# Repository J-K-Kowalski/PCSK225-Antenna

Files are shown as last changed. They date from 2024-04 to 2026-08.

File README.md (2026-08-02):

# PCSK225-Antenna

<ul>
<li>2026-08-02 - recalculate resistors value</li>
<li>2024-10-08 - fixed GND symbol</li>
<li>2024-06-18 - new version of Ferrite Holder</li>
</ul>

<p>This simple active antenna is designed to receive the time signal from the PCSK-225 transmitter in Solec Kujawski, Poland.

<p>It allows you to reliably receive UTC(pl) time frames transmitted by the <a href="https://e-czas.gum.gov.pl/e-czas-radio/" target=_blank>Central Office of Measures</a> using this transmitter. Receiver documentation is available at https://github.com/e-czasPL/TimeReceiver225kHz.

The project uses a ferrite antenna from a cheap and popular DCF receiver available, for example, on Aliexpress. Such an antenna has an inductance of approximately 1.5mH. You need to use 333pF capacitors (270pF + 56pF + trimmer 6-25pF) which will allow you to tune the resonant circuit to 225kHz.

The transistor BF545, MMBFJ108 (SMD) or BF245/J211 (THT) was used as an amplifier - only one should be installed.

If a long-wave ferrite antenna (from an old radio) with an inductance of about 4-6mH is used, the capacitors should be reduced to about 100pF.

<ul>
<li>In the /KiCAD folder, you will find a project in the KiCAD 10.0 format;
<li>In the /3D folder, you will find models of the holder and the entire antenna in STEP, STL formats;
</ul>

<p>The long wave signal of the First Polish Radio Program reaches a large part of Europe. You can see the coverage map below.

<p>
<table border=0 cellpadding=0 cellspacing=0 width=100%>
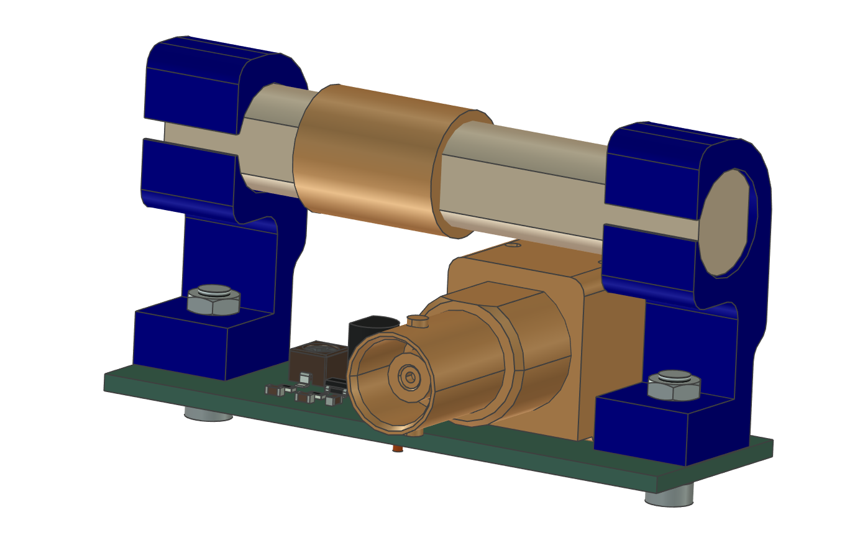
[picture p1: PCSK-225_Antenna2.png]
<tr><td>
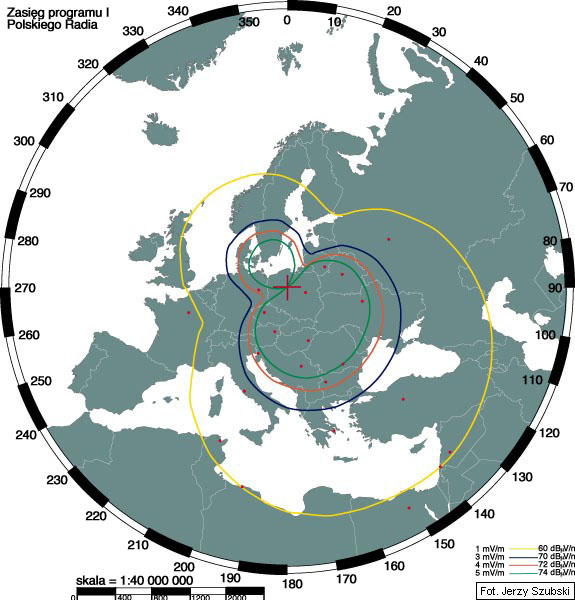
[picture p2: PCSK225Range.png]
</td><td></td></tr>
</table>

<ul>
<li>2024-06-18 - Nowa wersja modelu 3D do wydruku uchwytu na pręt ferrytowy</li>
</ul>

<p>Ta prosta aktywna antena jest zaprojektowana do odbioru sygnału czasu z nadajnika PCSK-225 w Solec Kujawski, Polska.

<p>Pozwala ona niezawodnie odbierać ramki czasu UTC(pl) nadawane przez <a href="https://e-czas.gum.gov.pl/e-czas-radio/" target=_blank>Główny Urząd Miar</a> za pomocą tego nadajnika. Dokumentacja odbiornika jest dostępna na https://github.com/e-CzasPL/TimeReceiver225kHz.

W projekcie użyto anteny ferrytowej od taniego i popularnego odbiornika DCF dostępnego np. na Aliexpress. Taka antena ma indukcyjność ok 1.5mH. Dlatego trzeba użyć kondensatorów 333pF (270pF + 56pF + trymer 6-25pF) co pozwoli zestroić obwód rezonansowy na 225 kHz.

Jako wzmacniacz użyto tranzystora BF545 lub MMBFJ108 (SMD) lub BF245/J211 (THT) - należy zamontować tylko jeden z nich.

Jeżeli zostanie użyta antena ferrytowa na fale długie (ze starego radia) o indukcyjności ok. 4-6mH to należy kondensatory zmniejszyć do ok 100pF.

<ul>
<li>W folderze /KiCAD znajdziesz projekt w formacie KiCAD 10;
<li>W folderze /3D znajdziesz modele uchwytu i całej anteny w formatach STEP, STL;
</ul>

<p>Sygnał fal długich Programu Pierwszego Polskiego Radia dociera do dużej części Europy. Powyżej możesz zobaczyć mapę zasięgu.

<p>Jerzy K. Kowalski<br>Marek Mańkowski

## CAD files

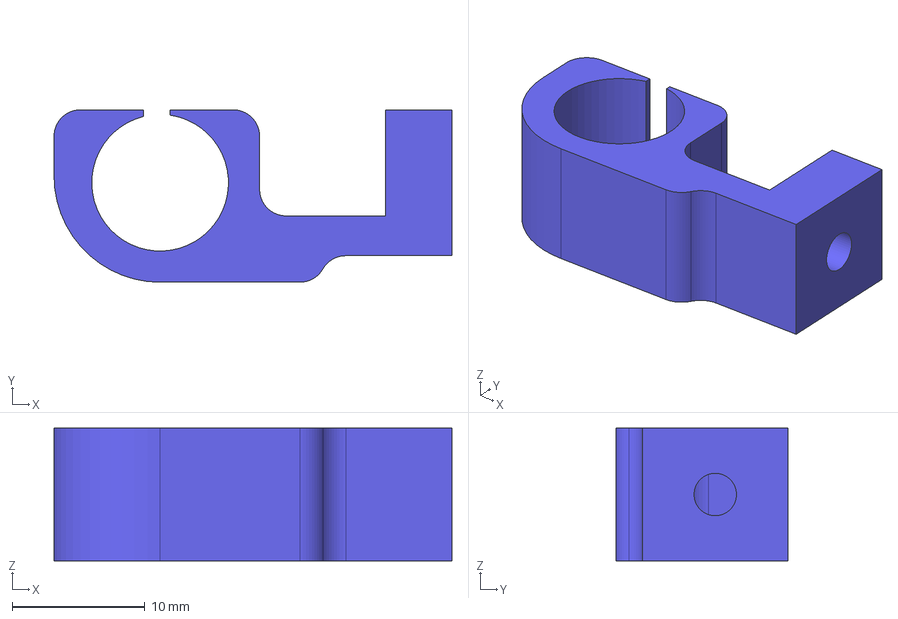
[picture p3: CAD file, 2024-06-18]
3D/FerriteHolder2.stp
30.0 x 13.0 x 10.00 mm

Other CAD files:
3D/FerriteHolder2.stl

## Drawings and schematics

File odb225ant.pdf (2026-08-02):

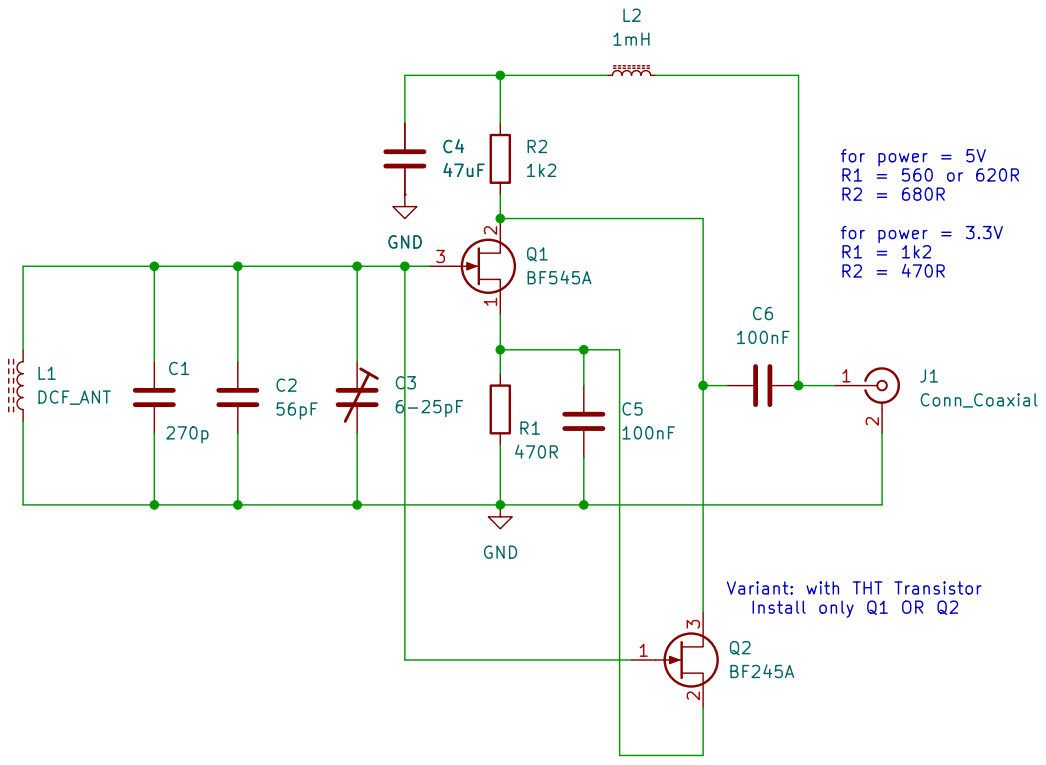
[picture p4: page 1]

Install only Q1 OR Q2 GND

Variant: with THT Transistor

Size: A4 | Rev:
KiCad E.D.A. 10.0.3 | Id: 1/1

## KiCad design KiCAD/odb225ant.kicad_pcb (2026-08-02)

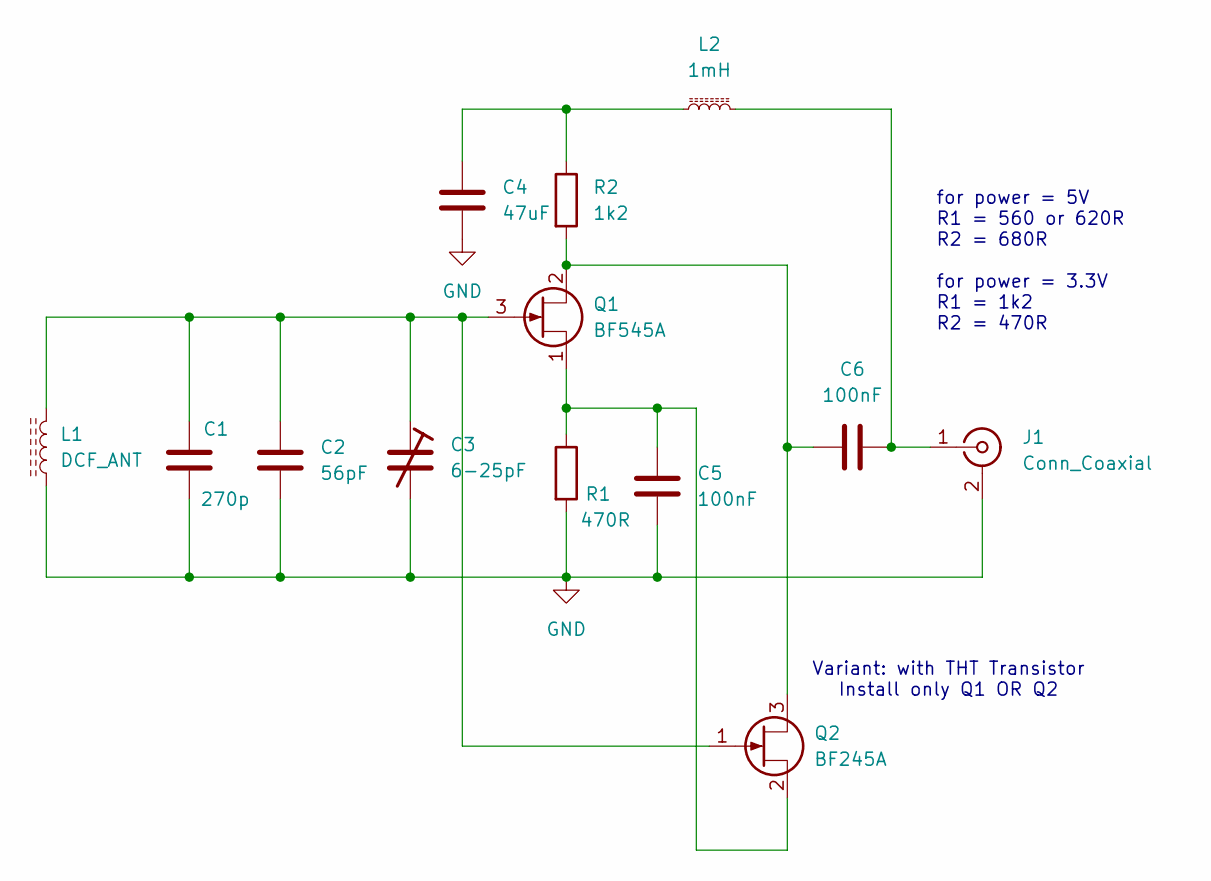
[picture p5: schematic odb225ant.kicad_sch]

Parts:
C1: 270p; C_0603_1608Metric_Pad1.08x0.95mm_HandSolder
C2: 56pF; C_0603_1608Metric_Pad1.08x0.95mm_HandSolder
C3: 6-25pF; C_Trimmer_Murata_TZB4-B
C4: 47uF; C_0603_1608Metric_Pad1.08x0.95mm_HandSolder
C5, C6: 100nF; C_0603_1608Metric_Pad1.08x0.95mm_HandSolder
J1: Conn_Coaxial; BNC_Horizontal
L1: DCF_ANT; PinHeader_1x02_P2.54mm_Vertical
L2: 1mH; L_Axial_L12.0mm_D5.0mm_P15.24mm_Horizontal_Fastron_MISC
Q1: BF545A; SOT-23
Q2: BF245A; TO-92_Inline
R1: 470R; R_0603_1608Metric_Pad0.98x0.95mm_HandSolder
R2: 1k2; R_0603_1608Metric_Pad0.98x0.95mm_HandSolder

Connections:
GND: C1.2, C2.2, C3.2, C4.2, C5.2, J1.2 (Ext), L1.2, R1.2
unnamed: C4.1, L2.1, R2.1
unnamed: C6.2, J1.1 (In), L2.2
unnamed: C6.1, Q1.2 (D), Q2.3 (D), R2.2
unnamed: C1.1, C2.1, C3.1, L1.1, Q1.3 (G), Q2.1 (G)
unnamed: C5.1, Q1.1 (S), Q2.2 (S), R1.1

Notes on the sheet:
Variant: with THT Transistor Install only Q1 OR Q2
for power = 5V R1 = 560 or 620R R2 = 680R for power = 3.3V R1 = 1k2 R2 = 470R

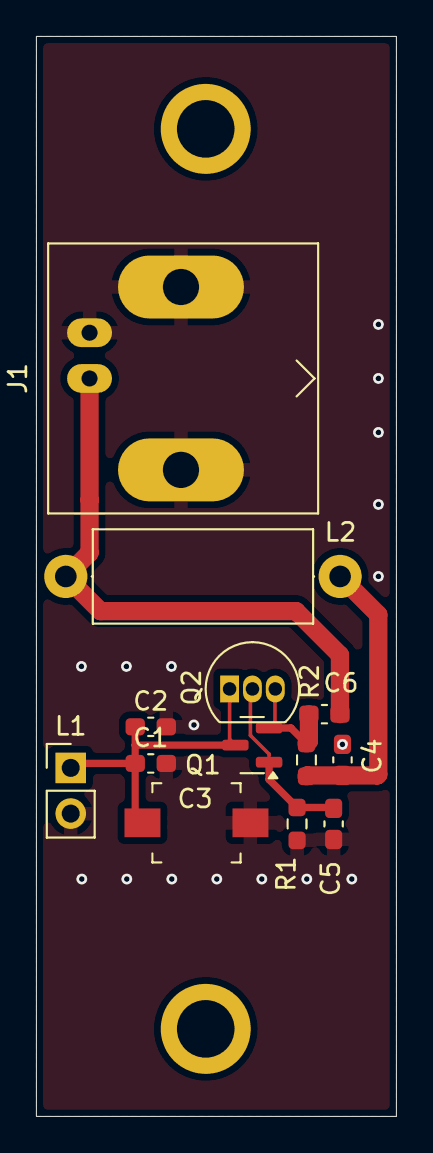
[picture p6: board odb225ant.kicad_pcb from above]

Board: 2 copper layers, 20.0 x 60.0 mm, 13 parts (0 on the bottom side), 6 nets.

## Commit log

2024-04-10 add project and 3D models
    [FerriteAntenna.stp, FerriteHolder.stl, FerriteHolder.stp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]
2024-04-10 modify readme
    [odb225ant.kicad_sch]
2024-06-18 FerriteHolder new model 3D
    [FerriteAntenna.stp, FerriteHolder.stl, FerriteHolder.stp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]
2024-10-08 fixed C4 GND symbol
    [odb225ant.kicad_sch]
2026-08-02 Calcutated resistor values for power 5V and 3.3V
    [odb225ant.kicad_pcb, odb225ant.kicad_sch]

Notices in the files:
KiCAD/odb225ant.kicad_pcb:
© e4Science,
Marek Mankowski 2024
